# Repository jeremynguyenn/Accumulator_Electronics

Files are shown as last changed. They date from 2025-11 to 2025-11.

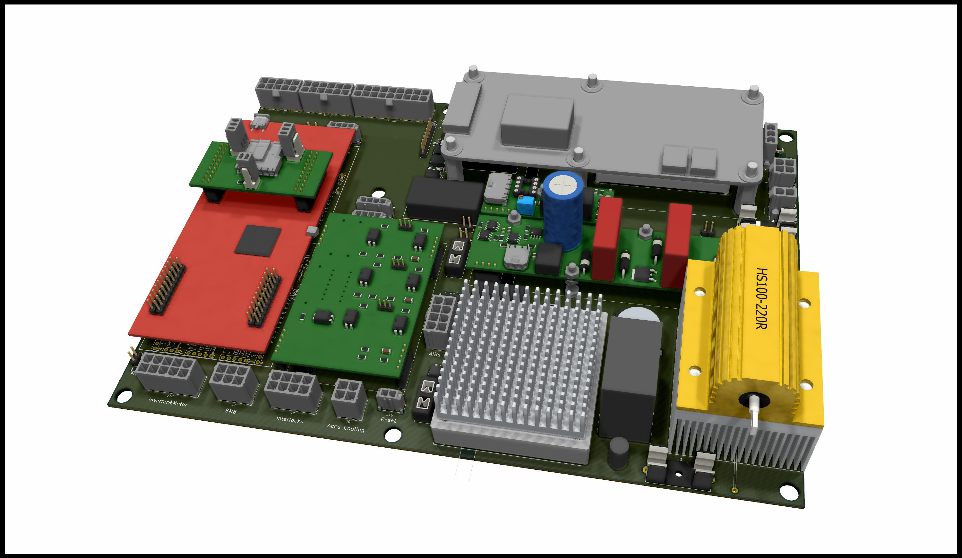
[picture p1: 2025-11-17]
Accumulator_Electronics/Accumulator Base/2021 Accumulator Base.png

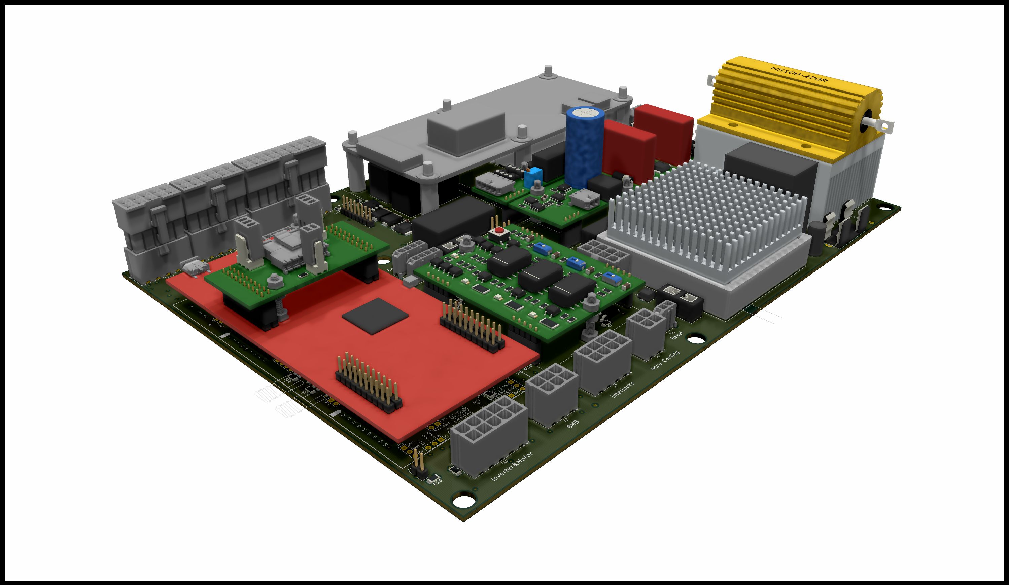
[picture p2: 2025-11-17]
Accumulator_Electronics/Accumulator Base/2021 Accumulator Base Final.png

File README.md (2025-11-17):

2021 Accumulator Base 2
2021 Accumulator Base Final
2021 Accumulator Base

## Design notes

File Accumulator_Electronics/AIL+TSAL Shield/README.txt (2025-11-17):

If all the CAD components can't be found in the 3D view is because some parts are referenced to a local folder
in another system. They can be downladed from the "KiCAD Libraries" repository found in Sabin's CADLAB.io account.
There is a link to such account in the team's GitHub, inside the "2021 Accumulator Electronics" repository.

**A component was created out of this PCB. It can be found in this very folder under "AIL&TSAL Library"

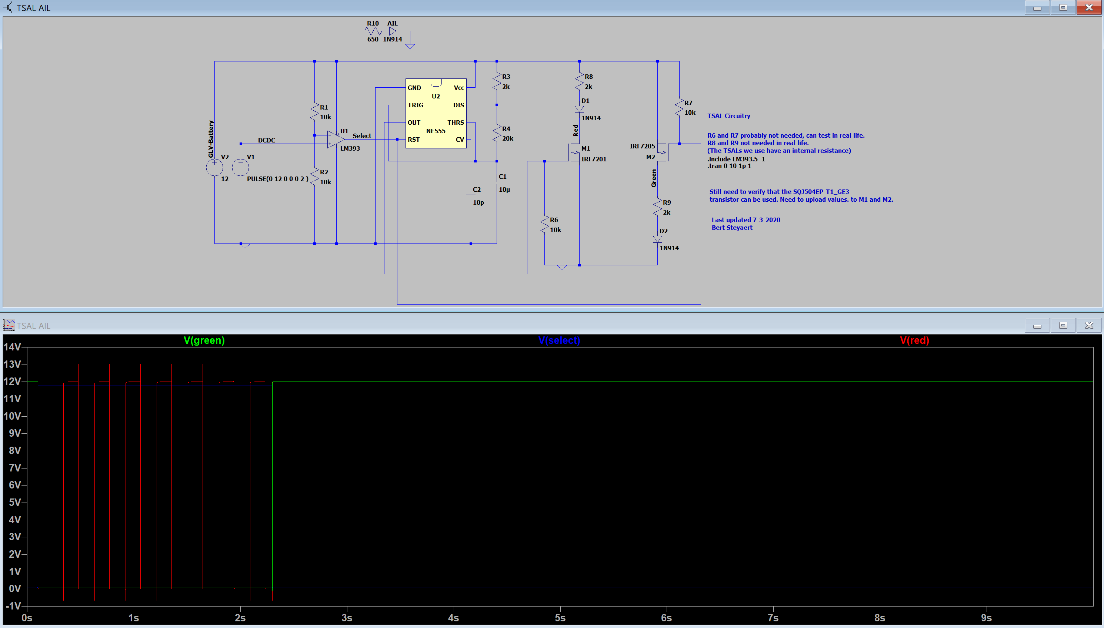
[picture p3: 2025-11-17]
Accumulator_Electronics/AIL+TSAL Shield/TSAL_Simulation/TSAL_final.png

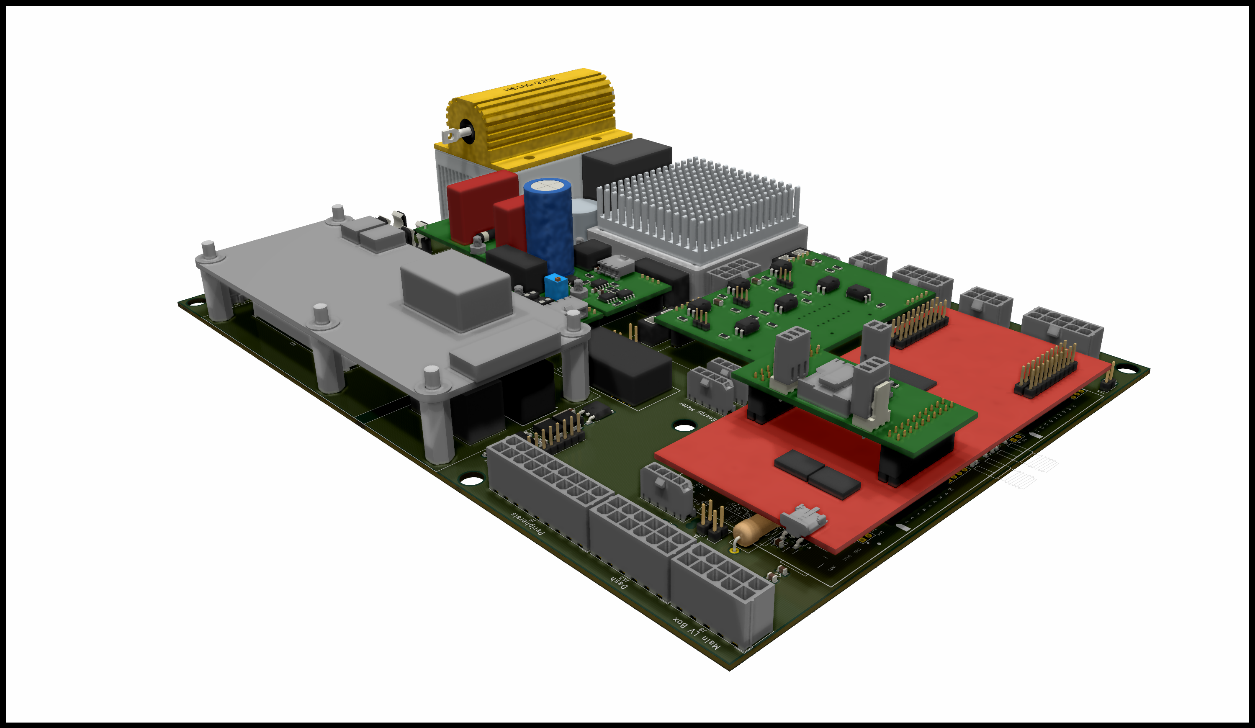
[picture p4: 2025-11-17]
Accumulator_Electronics/Accumulator Base/2021 Accumulator Base 2.png

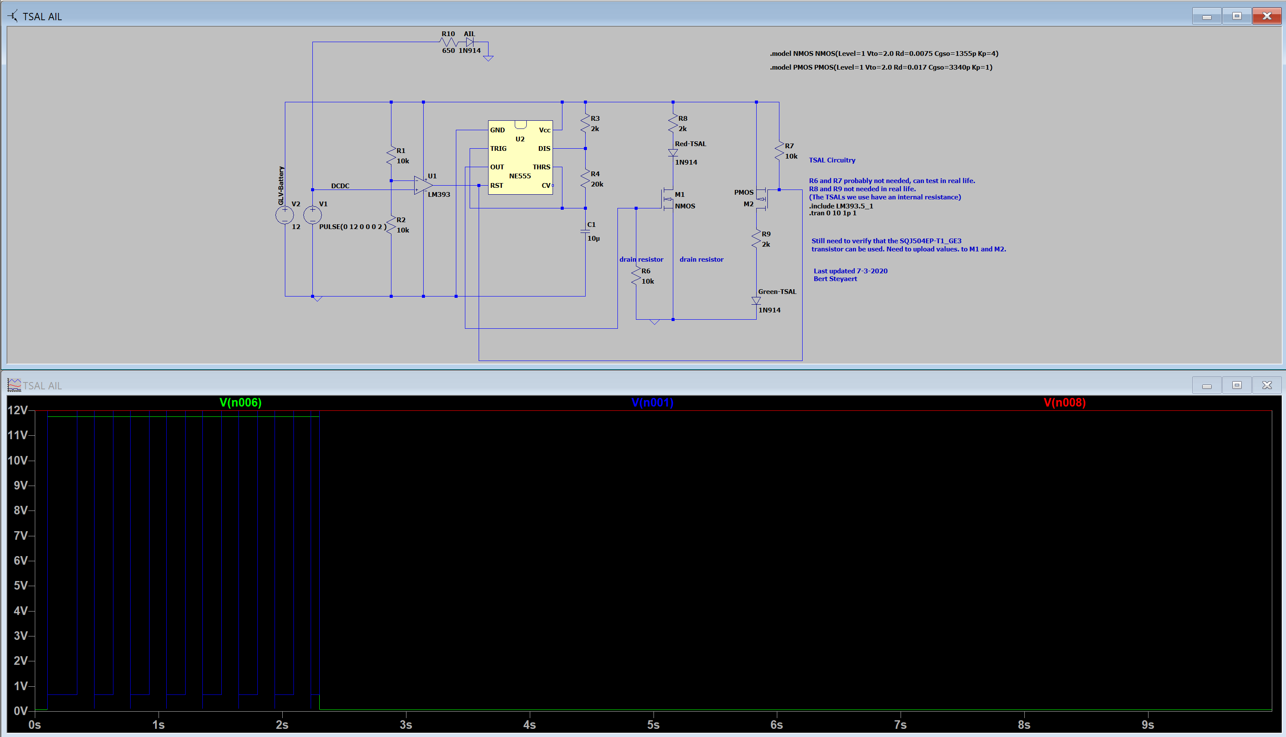
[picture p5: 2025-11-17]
Accumulator_Electronics/AIL+TSAL Shield/TSAL_Simulation/TSAL_SQJ504EP-T1_GE3.PNG

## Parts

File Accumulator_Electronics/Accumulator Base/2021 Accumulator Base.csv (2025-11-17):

Id | Designator | Package | Quantity | Designation | Supplier and ref
1 | U3 | SDC_9-8-20 | 1 | SDC_9-8-20
2 | U4 | LAUNCHXL-F28379D | 1 | LAUNCHXL-F28379D
3 | J3 | TE_MATE-N-LOK_1-770870-x_1x03_P4.14mm_Vertical | 1 | TSMP
4 | J10 | Molex_Mini-Fit_Jr_5566-10A_2x05_P4.20mm_Vertical | 1 | Inverter&Motor
5 | J2 | Molex_Mini-Fit_Jr_5566-06A_2x03_P4.20mm_Vertical | 1 | BMB
6 | J7 | Molex_Mini-Fit_Jr_5566-08A_2x04_P4.20mm_Vertical | 1 | Interlocks
7 | J6 | Molex_Mini-Fit_Jr_5566-04A_2x02_P4.20mm_Vertical | 1 | Accu Cooling
8 | J9 | Molex_Mini-Fit_Jr_5566-08A_2x04_P4.20mm_Vertical | 1 | AIRs
9 | C1 | CAPPRD250W50D655H1250 | 1 | 1u
10 | C2 | CAPAE1700X1700N | 1 | 10u
11 | C3,C5 | C_0805_2012Metric | 2 | 10u
12 | C4 | C_0805_2012Metric | 1 | 4.7u
13 | C6,C8,C10,C11,C12,C13,C14,C15,C16 | C_0805_2012Metric | 9 | 100n
14 | C7,C9 | C_0805_2012Metric | 2 | 10n
15 | D1,D2 | D_SMC | 2 | STTH212S
16 | D3,D4,D7 | D_0805_2012Metric | 3 | LED
17 | D5,D6 | D_SMC | 2 | D
18 | D8 | D_SOD-323 | 1 | DIODE
19 | F4 | Fuseholder_Blade_Mini_Keystone_3568 | 1 | 25A
20 | F6 | Fuseholder_Blade_Mini_Keystone_3568 | 1 | Fuse
21 | J11,J14,J15,J1,J18 | PinHeader_1x02_P2.54mm_Vertical | 5 | Jumper
22 | J16 | Molex_Micro-Fit_3.0_43650-0215_1x02_P3.00mm_Vertical | 1 | Reset button
23 | K1 | H3FA-A | 1 | Relay_H3FA-A-DC12
24 | L2 | L_1210_3225Metric | 1 | 10u
25 | Q1,Q2,Q3,Q4,Q6,Q7,Q8 | TO-252-2 | 7 | Q_NMOS_GDS
26 | Q5,Q10,Q11,Q12,Q13,Q14,Q15,Q16,Q17,Q18,Q19,Q20,Q21 | SOT-223-3_TabPin2 | 13 | Q_NMOS_GDS
27 | R1,R2,R7,R11,R17,R18,R19,R20,R21,R22,R23,R24,R25,R26,R27,R28,R29,R9,R13,R15,R30,R32,R33,R35,R36,R37,R38,R39,R40,R41,R42,R43,R44,R45,R46,R47,R48,R49 | R_1206_3216Metric | 38 | 10k
28 | R3,R4,R5,R14 | R_1206_3216Metric | 4 | 2k
29 | R6 | HS100 | 1 | HS100 2K F
30 | R8,R10,R12 | R_1206_3216Metric | 3 | NC
31 | R16 | R_1206_3216Metric | 1 | 120
32 | R31 | R_Axial_DIN0617_L17.0mm_D6.0mm_P20.32mm_Horizontal | 1 | R_US
33 | RV1 | Potentiometer_Vishay_TS53YJ_Vertical | 1 | TS53YJ501MR10
34 | U1 | 74HC86DR2G | 1 | 74HC86
35 | U5 | PWR_Transducer | 1 | PWR_Transducer
36 | U6 | Converter_DCDC_Murata_NCS1SxxxxSC_THT | 1 | NCS1S1212SC
37 | U8 | AIL&TSAL | 1 | AIL&TSAL
38 | U9 | TSOT-23-5 | 1 | LM3670MF
39 | U10 | G2RL112DC | 1 | G2RL-1-DC12.
40 | U11 | G2RL-24 | 1 | G2RL-24-DC12
41 | U12 | DBR71210 | 1 | DBR71210
42 | U13 | DAR71210 | 1 | DAR71210
43 | L1 | B82724J8612N040 | 1 | B82724J8612N040
44 | U2 | IMD | 1 | IMD
45 | U7 | QHL300 | 1 | QHL300
46 | F1,F2,F5 | Fuseholder_Cylinder-5x20mm_Schurter_0031_8201_Horizontal_Open | 3 | Fuse
47 | F3 | Fuseholder_Cylinder-5x20mm_Schurter_0031_8201_Horizontal_Open | 1 | 5A
48 | F7 | Fuse_1206_3216Metric | 1 | Fuse
49 | J4 | Molex_Mini-Fit_Jr_5566-04A2_2x02_P4.20mm_Vertical | 1 | Inv&Bat+
50 | J5 | Molex_Mini-Fit_Jr_5566-18A_2x09_P4.20mm_Vertical | 1 | Peripherals
51 | J8 | Molex_Mini-Fit_Jr_5566-10A_2x05_P4.20mm_Vertical | 1 | Main LV
52 | J12 | Molex_Micro-Fit_3.0_43650-0415_1x04_P3.00mm_Vertical | 1 | EnergyMeter-OUT
53 | J13 | Molex_Mini-Fit_Jr_5566-12A_2x06_P4.20mm_Vertical | 1 | Dash
54 | J17 | Molex_Mini-Fit_Jr_5566-02A2_2x01_P4.20mm_Vertical | 1 | Inverter-
55 | J19 | Molex_Micro-Fit_3.0_43650-0415_1x04_P3.00mm_Vertical | 1 | EnergyMeter-IN
56 | J20 | Molex_Micro-Fit_3.0_43650-0415_1x04_P3.00mm_Vertical | 1 | LCD

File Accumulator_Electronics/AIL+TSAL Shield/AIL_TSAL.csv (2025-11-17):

Id | Designator | Package | Quantity | Designation | Supplier and ref
1 | J3 | Molex_Micro-Fit_3.0_43650-0200_1x02_P3.00mm_Horizontal | 1 | Conn_01x02
2 | C1 | C_Rect_L27.0mm_W9.0mm_P22.00mm | 1 | 0.1uF
3 | C2 | C_Rect_L27.0mm_W9.0mm_P22.00mm | 1 | 1uF
4 | C3 | C_Radial_D16.0mm_H31.5mm_P7.50mm | 1 | 47uF
5 | C4 | C_0805_2012Metric | 1 | 27uF
6 | C5 | C_0805_2012Metric | 1 | 0.01u
7 | C6 | C_0805_2012Metric | 1 | 10u
8 | D1,D3 | D_5W_P10.16mm_Horizontal | 2 | DIODE
9 | D2 | D_5W_P10.16mm_Horizontal | 1 | D_Zener
10 | F1 | Fuse_1206_3216Metric | 1 | 50mA
11 | J1,J2 | Pin_D1.0mm_L10.0mm | 2 | Conn_01x01
12 | Q1 | SO-8_3.9x4.9mm_P1.27mm | 1 | Q_NMOS_SGD | IRF7201
13 | Q2 | SO-8_3.9x4.9mm_P1.27mm | 1 | Q_PMOS_SDG | IRF7205
14 | R1 | D_5W_P12.70mm_Horizontal | 1 | 48k
15 | R2 | D_5W_P12.70mm_Horizontal | 1 | 2k
16 | R3,R4,R8,R9 | R_1206_3216Metric | 4 | 10k
17 | R5 | R_1206_3216Metric | 1 | 650
18 | R6 | R_1206_3216Metric | 1 | 2k
19 | R7 | R_1206_3216Metric | 1 | 20k
20 | U1 | TO-252-2 | 1 | LR8K4-G
21 | U2 | PQP1-D24-D12-D | 1 | CRE1S0505DC | PQP1-D24-D12-D
22 | U3 | SOIC-8_3.9x4.9mm_P1.27mm | 1 | LM741 | LM393
23 | U4 | SOIC-8_3.9x4.9mm_P1.27mm | 1 | LM555
24 | J4 | PinHeader_1x04_P2.54mm_Vertical | 1 | Conn_01x04

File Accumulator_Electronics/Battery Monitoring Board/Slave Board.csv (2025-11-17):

Id | Designator | Package | Quantity | Designation | Supplier and ref
1 | J13 | Molex_Micro-Fit_3.0_43045-0800_2x04_P3.00mm_Horizontal | 1 | Conn_01x08
2 | U1 | MCP2515_ArduinoShield | 1 | MCP2551_CANmodule
3 | G***,G*** | flag | 2 | LOGO
4 | R12 | R_0805_2012Metric | 1 | NC
5 | J20,J14,J15,J16,J17,J18,J19,J21,J22,J23,J24,J25,J26 | TE_MATE-N-LOK_1-794374-x_1x01_P4.14mm_Horizontal | 13 | Conn_01x01
6 | C1,C3,C6,C7,C8,C9,C10,C11,C12,C13 | C_0805_2012Metric | 10 | 100n
7 | C2,C4,C5 | C_0805_2012Metric | 3 | 1u
8 | C14,C15,C16,C17,C18,C19,C20,C21,C22,C23,C24,C25 | C_0805_2012Metric | 12 | 10n
9 | D1 | D_1206_3216Metric | 1 | DIODE
10 | F1,F2,F3,F4,F5,F6,F7,F8,F9,F10,F11,F12,F13 | Fuse_1206_3216Metric | 13 | Fuse
11 | IC1 | SOP50P490X110-16N | 1 | LTC6820IMS#PBF
12 | IC2 | SOP50P780X200-48N | 1 | LTC6804-2
13 | J1,J2,J3,J4,J5,J6,J7,J8,J9,J10,J11,J12 | TE_MATE-N-LOK_1-770966-x_1x02_P4.14mm_Horizontal | 12 | Conn_01x02
14 | Q1 | SOT-223 | 1 | Q_NPN_BCE
15 | Q2,Q3,Q4,Q5,Q6,Q7,Q8,Q9,Q10,Q11,Q12,Q13 | SOT-23 | 12 | Q_PMOS_GSD
16 | R1,R2,R3,R4,R5,R6,R7,R8,R9,R10,R11,R60 | R_1206_3216Metric | 12 | 680
17 | R13 | R_0805_2012Metric | 1 | 5k
18 | R14,R15,R18,R22,R23,R25,R28,R31,R34,R37,R40,R43,R46,R49,R52,R55,R58 | R_0805_2012Metric | 17 | 100
19 | R16,R20 | R_0805_2012Metric | 2 | 1k21
20 | R17,R21 | R_0805_2012Metric | 2 | 860
21 | R19 | R_0805_2012Metric | 1 | 10k
22 | R24,R27,R30,R33,R36,R39,R42,R45,R48,R51,R54,R57 | R_0805_2012Metric | 12 | 3k3
23 | R26,R29,R32,R35,R38,R41,R44,R47,R50,R53,R56,R59 | R_0805_2012Metric | 12 | 33
24 | T1 | Pulse_PA2001NL | 1 | PE-68386NL
25 | U2 | SOIC-8_3.9x4.9mm_P1.27mm | 1 | MCP2551-I-SN
26 | U3 | SOT-223 | 1 | OKI-78SR-3.3_1.5-W36-C
27 | U4 | SOP-8_6.62x9.15mm_P2.54mm | 1 | ISO1050DUB
28 | U5 | Converter_DCDC_TRACO_POWER_TEL_10-xxxx_THT | 1 | TMR_1-1212
29 | U6 | Arduino_Micro_Socket | 1 | ARDUINO_MICRO_SHIELD
30 | J27 | Molex_KK-254_AE-6410-04A_1x04_P2.54mm_Vertical | 1 | Conn_01x04

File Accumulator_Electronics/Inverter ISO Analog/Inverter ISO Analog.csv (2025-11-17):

Id | Designator | Package | Quantity | Designation | Supplier and ref
1 | J4 | Molex_KK-254_AE-6410-03A_1x03_P2.54mm_Vertical | 1 | Accelerator Sensor
2 | J3 | Molex_KK-254_AE-6410-02A_1x02_P2.54mm_Vertical | 1 | Motor
3 | J2 | Molex_KK-254_AE-6410-03A_1x03_P2.54mm_Vertical | 1 | Brake Sensor
4 | J1 | Molex_Micro-Fit_3.0_43650-0500_1x05_P3.00mm_Horizontal | 1 | Inverter
5 | R1 | R_1206_3216Metric | 1 | 330k
6 | U1 | C2000BoosterPack_Shield | 1 | C2000BoosterPack_Shield

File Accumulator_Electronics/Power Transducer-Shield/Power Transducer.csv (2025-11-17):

Id | Designator | Package | Quantity | Designation | Supplier and ref
1 | RV1 | Potentiometer_ACP_CA9-H2,5_Horizontal | 1 | 100k
2 | C1 | C_0805_2012Metric | 1 | 10n
3 | C2,C7 | C_0805_2012Metric | 2 | 1u
4 | C3,C4,C5,C6 | C_0805_2012Metric | 4 | 0.1u
5 | D1,D2 | D_0805_2012Metric | 2 | DIODE
6 | IC1 | SOIC127P1150X280-8N | 1 | AMC1211AQDWVRQ1
7 | IC2 | DIP794W53P254L959H508Q8N | 1 | INA114AP
8 | J1,J2 | Pin_D1.0mm_L10.0mm | 2 | Conn_01x01
9 | J3 | Molex_Micro-Fit_3.0_43650-0400_1x04_P3.00mm_Horizontal | 1 | Conn_01x04
10 | J4 | PinHeader_1x05_P2.54mm_Vertical | 1 | Conn_01x05
11 | PS1 | Converter_DCDC_XP_POWER-ITXxxxxSA_THT | 1 | ITX0505SA
12 | R1,R2,R3 | R_1206_3216Metric | 3 | 3M
13 | R4 | R_1206_3216Metric | 1 | 59k

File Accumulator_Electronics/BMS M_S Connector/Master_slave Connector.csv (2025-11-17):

Id | Designator | Package | Quantity | Designation | Supplier and ref
1 | J2,J3,J4,J5,J6,J7 | Molex_Micro-Fit_3.0_43045-0812_2x04_P3.00mm_Vertical | 6 | Conn_01x08
2 | J1 | Molex_Mini-Fit_Jr_5566-06A_2x03_P4.20mm_Vertical | 1 | Conn_01x06
3 | J8 | Molex_Mini-Fit_Jr_5566-04A_2x02_P4.20mm_Vertical | 1 | Conn_01x04

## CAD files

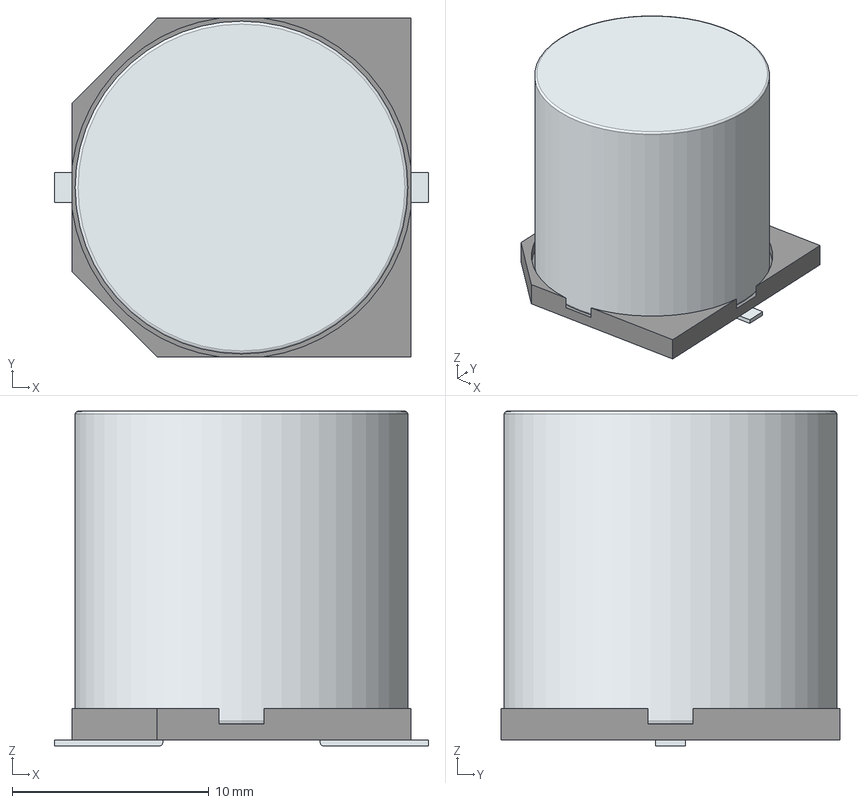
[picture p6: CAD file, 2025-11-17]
Accumulator_Electronics/Accumulator Base/EEV-EB2V100SM/3D/EEV-EB2V100SM.stp
19.0 x 17.2 x 17.0 mm
Base
Pin1Fillet
Pin2Fillet

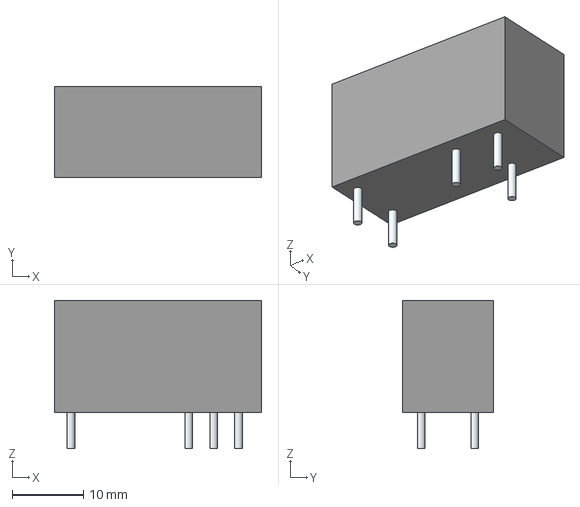
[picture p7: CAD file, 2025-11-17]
Accumulator_Electronics/Accumulator Base/G2RL-1_12DC/3D/G2RL-1_12DC.stp
29.0 x 12.7 x 20.8 mm
Leads x 5

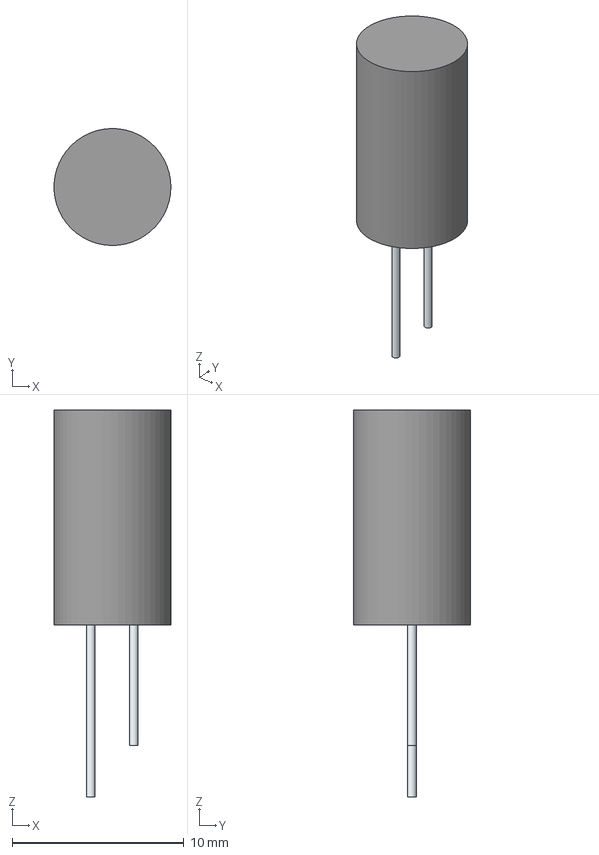
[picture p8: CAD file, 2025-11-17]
Accumulator_Electronics/Accumulator Base/UVR2V010MED/3D/UVR2V010MED.stp
6.79 x 6.80 x 22.5 mm
SimpleBody
Pin1
Pin2

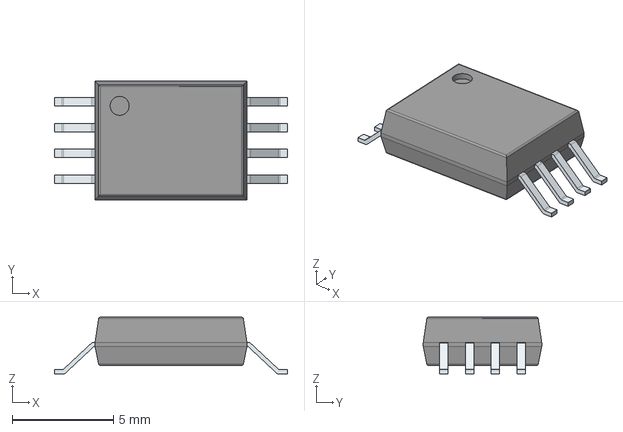
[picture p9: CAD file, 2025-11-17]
Accumulator_Electronics/Power Transducer-Shield/07-02-2020/AMC1211AQDWVRQ1/3D/AMC1211AQDWVRQ1.stp
11.5 x 5.85 x 2.80 mm
PinsArrayLR

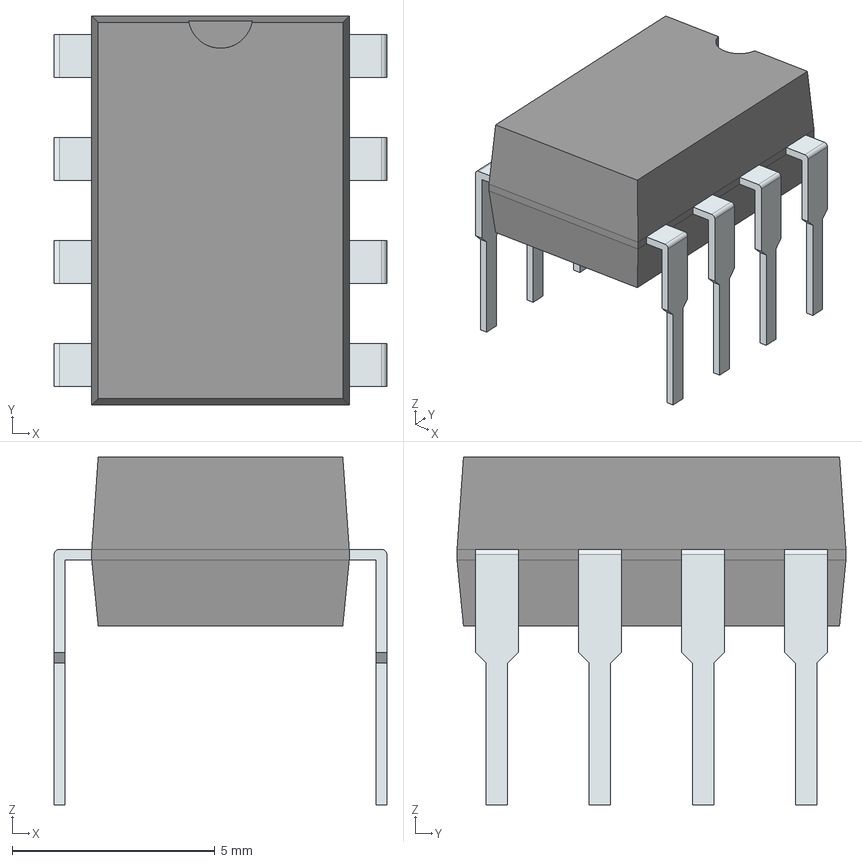
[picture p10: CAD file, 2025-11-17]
Accumulator_Electronics/Power Transducer-Shield/07-02-2020/INA114AP/3D/INA114AP.stp
8.21 x 9.59 x 8.58 mm
PinsArrayLR

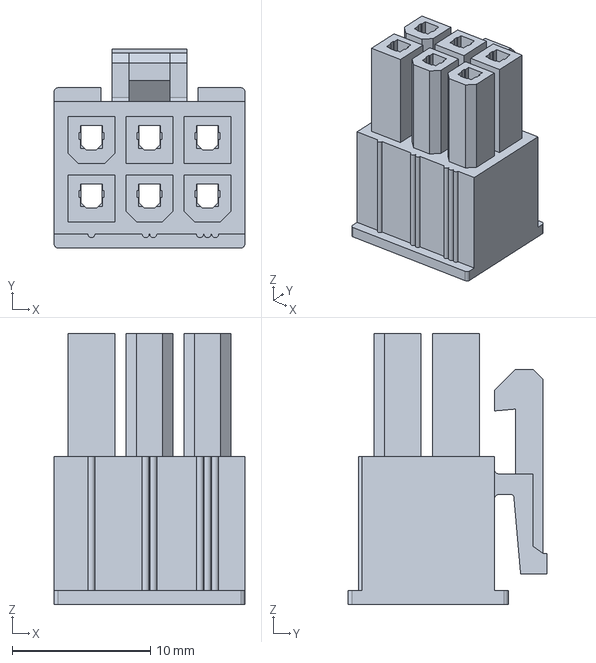
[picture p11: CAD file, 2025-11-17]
Accumulator_Electronics/BMS M_S Connector/8-1-2020/3D/39-01-2060.stp
13.8 x 14.4 x 19.6 mm

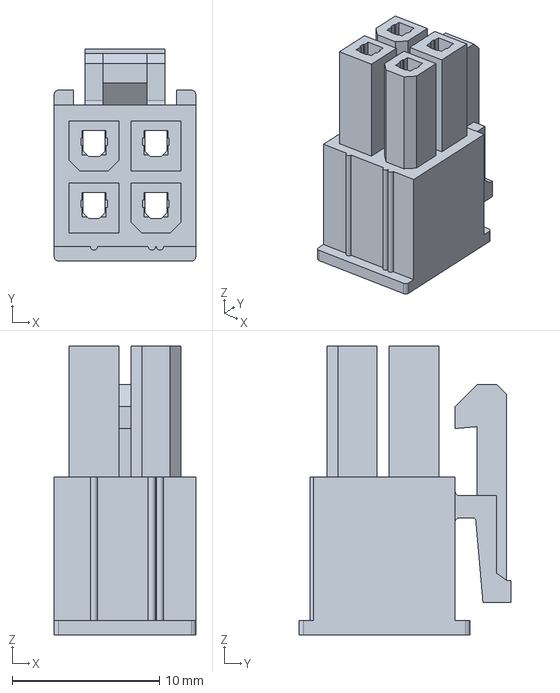
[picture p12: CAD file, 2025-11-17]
Accumulator_Electronics/BMS M_S Connector/8-1-2020/3D/39-01-2045.stp
9.60 x 14.4 x 19.6 mm

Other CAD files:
Accumulator_Electronics/Accumulator Base/2021 Accumulator Base.step
Accumulator_Electronics/Accumulator Base/CAD Models/1 Row Female Pin Header Pitch 2.54mm Height 8.5mm/Female Pin Header 01x05 Pitch 2.54mm Height 8.5mm.stp
Accumulator_Electronics/Accumulator Base/CAD Models/Accumulator Box/SDC_module v1.step
Accumulator_Electronics/AIL+TSAL Shield/07-10-2020/AIL_TSAL.step
Accumulator_Electronics/Battery Monitoring Board/09-07-2020 BMB/LTC6804-2/3D/LTC6804-2.stp
Accumulator_Electronics/Battery Monitoring Board/09-07-2020 BMB/LTC6820IMS#PBF/3D/LTC6820IMS#PBF.stp
Accumulator_Electronics/Battery Monitoring Board/09-07-2020 BMB/Slave Board.step
Accumulator_Electronics/BMS M_S Connector/8-1-2020/Master_slave Connector.step
Accumulator_Electronics/Inverter ISO Analog/Inverter ISO Analog.step
Accumulator_Electronics/Power Transducer-Shield/07-02-2020/Power Transducer.step
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

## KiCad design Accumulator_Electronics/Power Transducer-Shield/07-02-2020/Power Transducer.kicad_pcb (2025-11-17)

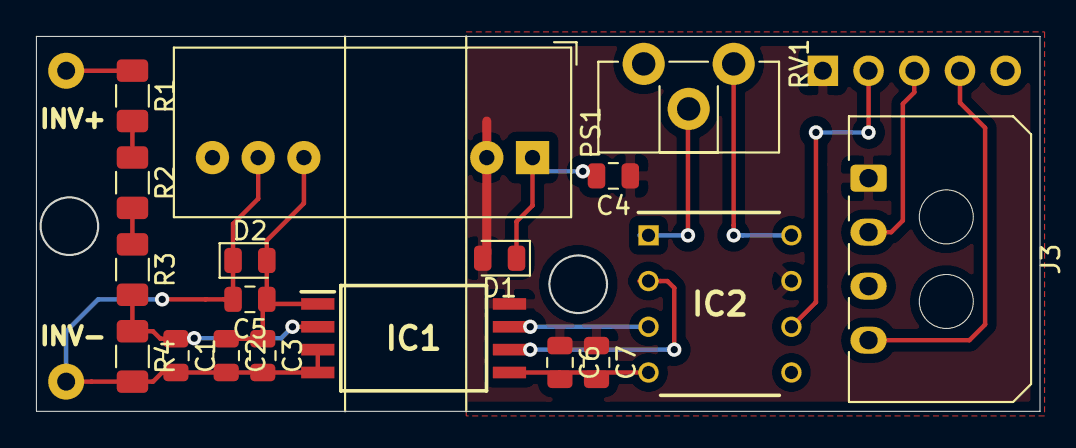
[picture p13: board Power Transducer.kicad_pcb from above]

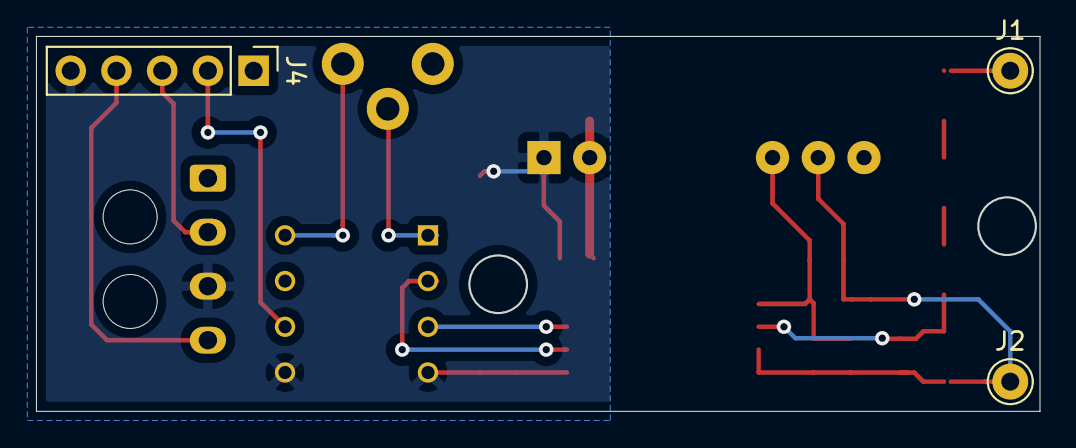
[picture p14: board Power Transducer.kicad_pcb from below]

Board: 2 copper layers, 55.8 x 20.8 mm, 21 parts (3 on the bottom side), 15 nets.

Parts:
C1: 10n; C_0805_2012Metric
C2, C7: 1u; C_0805_2012Metric
C3, C4, C5, C6: 0.1u; C_0805_2012Metric
D1, D2: DIODE; D_0805_2012Metric
IC1: AMC1211AQDWVRQ1; SOIC127P1150X280-8N
IC2: INA114AP; DIP794W53P254L959H508Q8N
J1, J2: Conn_01x01; Pin_D1.0mm_L10.0mm
J3: Conn_01x04; Molex_Micro-Fit_3.0_43650-0400_1x04_P3.00mm_Horizontal
J4: Conn_01x05; PinHeader_1x05_P2.54mm_Vertical
PS1: ITX0505SA; Converter_DCDC_XP_POWER-ITXxxxxSA_THT
R1, R2, R3: 3M; R_1206_3216Metric
R4: 59k; R_1206_3216Metric
RV1: 100k; Potentiometer_ACP_CA9-H2,5_Horizontal

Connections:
+5V: C4.1, C6.1, C7.1, D1.2, IC1.8, IC2.7, J3.1, J4.1, PS1.2
GND: C4.2, C6.2, C7.2, D1.1, IC1.5, IC2.4, IC2.5, J3.3, J4.5, PS1.1
HV_Sens: IC2.6, J4.2
High_C_Meas: J3.2, J4.3
Inv+: J1.1, R1.1
Inv-: C1.2, C2.2, C3.2, C5.2, D2.1, IC1.3, IC1.4, J2.1, PS1.7, R4.2
Low_C_Meas: J3.4, J4.4
unnamed: C1.1, IC1.2, R3.2, R4.1
unnamed: IC1.6, IC2.2
unnamed: IC1.7, IC2.3
unnamed: IC2.1, RV1.2
unnamed: IC2.8, RV1.1
unnamed: R1.2, R2.1
unnamed: R2.2, R3.1
VDD1: C2.1, C3.1, C5.1, D2.2, IC1.1, PS1.6

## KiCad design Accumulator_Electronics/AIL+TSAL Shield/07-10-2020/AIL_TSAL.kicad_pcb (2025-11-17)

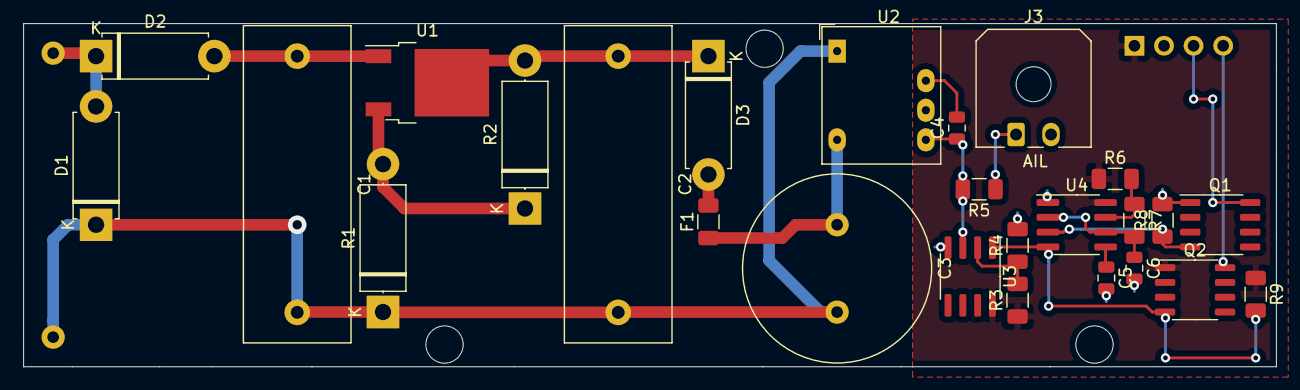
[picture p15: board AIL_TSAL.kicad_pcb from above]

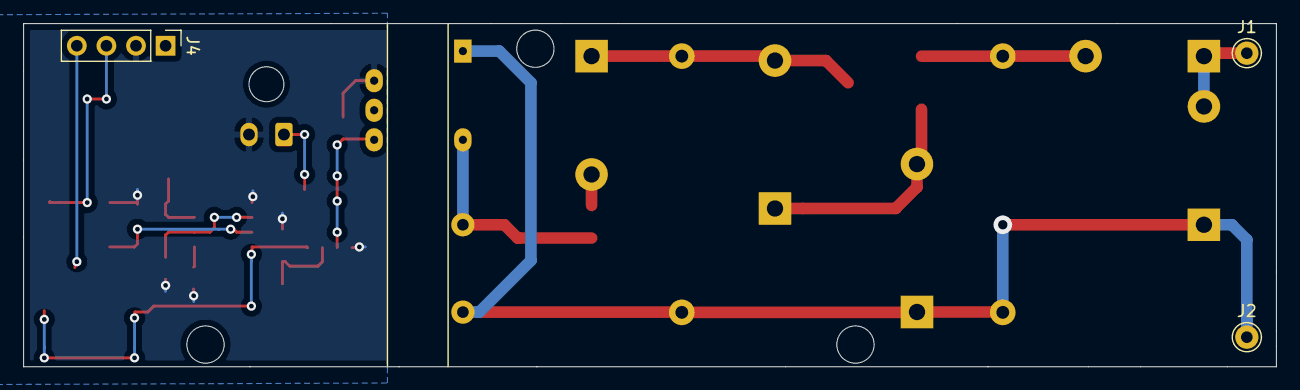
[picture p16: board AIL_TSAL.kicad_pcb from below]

Board: 2 copper layers, 107.6 x 29.5 mm, 29 parts (3 on the bottom side), 19 nets.

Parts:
C1: 0.1uF; C_Rect_L27.0mm_W9.0mm_P22.00mm
C2: 1uF; C_Rect_L27.0mm_W9.0mm_P22.00mm
C3: 47uF; C_Radial_D16.0mm_H31.5mm_P7.50mm
C4: 27uF; C_0805_2012Metric
C5: 0.01u; C_0805_2012Metric
C6: 10u; C_0805_2012Metric
D1, D3: DIODE; D_5W_P10.16mm_Horizontal
D2: D_Zener; D_5W_P10.16mm_Horizontal
F1: 50mA; Fuse_1206_3216Metric
J1, J2: Conn_01x01; Pin_D1.0mm_L10.0mm
J3: Conn_01x02; Molex_Micro-Fit_3.0_43650-0200_1x02_P3.00mm_Horizontal
J4: Conn_01x04; PinHeader_1x04_P2.54mm_Vertical
Q1: Q_NMOS_SGD; SO-8_3.9x4.9mm_P1.27mm
Q2: Q_PMOS_SDG; SO-8_3.9x4.9mm_P1.27mm
R1: 48k; D_5W_P12.70mm_Horizontal
R2: 2k; D_5W_P12.70mm_Horizontal
R3, R4, R8, R9: 10k; R_1206_3216Metric
R5: 650; R_1206_3216Metric
R6: 2k; R_1206_3216Metric
R7: 20k; R_1206_3216Metric
U1: LR8K4-G; TO-252-2
U2: CRE1S0505DC; PQP1-D24-D12-D
U3: LM741; SOIC-8_3.9x4.9mm_P1.27mm
U4: LM555; SOIC-8_3.9x4.9mm_P1.27mm

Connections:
+12V: J4.1, Q2.1, R3.1, R6.1, R9.1, U3.8, U4.8
/Sheet5F0851A9/Inv+: D1.2, D2.1, J1.1
/Sheet5F0851A9/Inv-: C1.2, C2.2, C3.2, D1.1, J2.1, R1.1, U2.1
GND: C4.2, C5.2, C6.2, J3.2, J4.2, Q1.1, R4.2, R8.2, U2.7, U3.4, U4.1
Green+: J4.4, Q2.8
unnamed: C1.1, D2.2, U1.1
unnamed: C2.1, D3.1, R2.2, U1.2
unnamed: C3.1, F1.1, U2.4
unnamed: C4.1, R5.2, U2.5, U3.3
unnamed: C5.1, U4.5
unnamed: C6.1, R7.2, U4.2, U4.6
unnamed: D3.2, F1.2
unnamed: J3.1, R5.1
unnamed: Q1.4, R8.1, U4.3
unnamed: Q2.4, R9.2, U3.1, U4.4
unnamed: R1.2, R2.1, U1.3
unnamed: R3.2, R4.1, U3.2
unnamed: R6.2, R7.1, U4.7
Red-: J4.3, Q1.8

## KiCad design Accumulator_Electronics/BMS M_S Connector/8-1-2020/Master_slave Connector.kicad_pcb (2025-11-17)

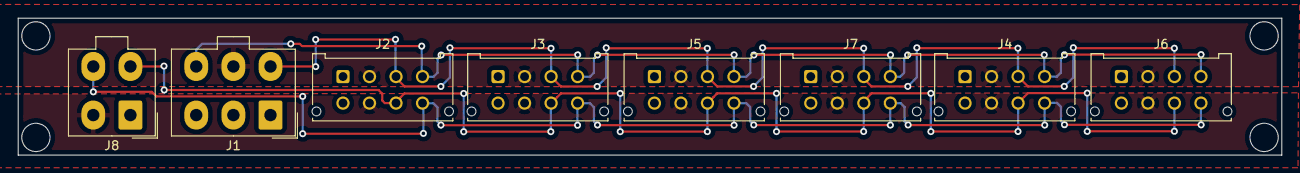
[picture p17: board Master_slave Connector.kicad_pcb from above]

Board: 2 copper layers, 143.0 x 15.5 mm, 8 parts (0 on the bottom side), 7 nets.

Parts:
J1: Conn_01x06; Molex_Mini-Fit_Jr_5566-06A_2x03_P4.20mm_Vertical
J2, J3, J4, J5, J6, J7: Conn_01x08; Molex_Micro-Fit_3.0_43045-0812_2x04_P3.00mm_Vertical
J8: Conn_01x04; Molex_Mini-Fit_Jr_5566-04A_2x02_P4.20mm_Vertical

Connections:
+12V: J1.5, J2.2, J3.2, J4.2, J5.2, J6.2, J7.2
CANH: J1.4, J2.3, J3.3, J4.3, J5.3, J6.3, J7.3
CANL: J1.6, J2.4, J3.4, J4.4, J5.4, J6.4, J7.4
DCDC+: J2.6, J3.6, J4.6, J5.6, J6.6, J7.6, J8.2
GND: J1.1, J1.2, J2.1, J2.5, J3.1, J3.5, J4.1, J4.5, J5.1, J5.5, J6.1, J6.5, J7.1, J7.5, J8.1
PWM: J2.8, J3.8, J4.8, J5.8, J6.8, J7.8, J8.4
Sens: J2.7, J3.7, J4.7, J5.7, J6.7, J7.7, J8.3

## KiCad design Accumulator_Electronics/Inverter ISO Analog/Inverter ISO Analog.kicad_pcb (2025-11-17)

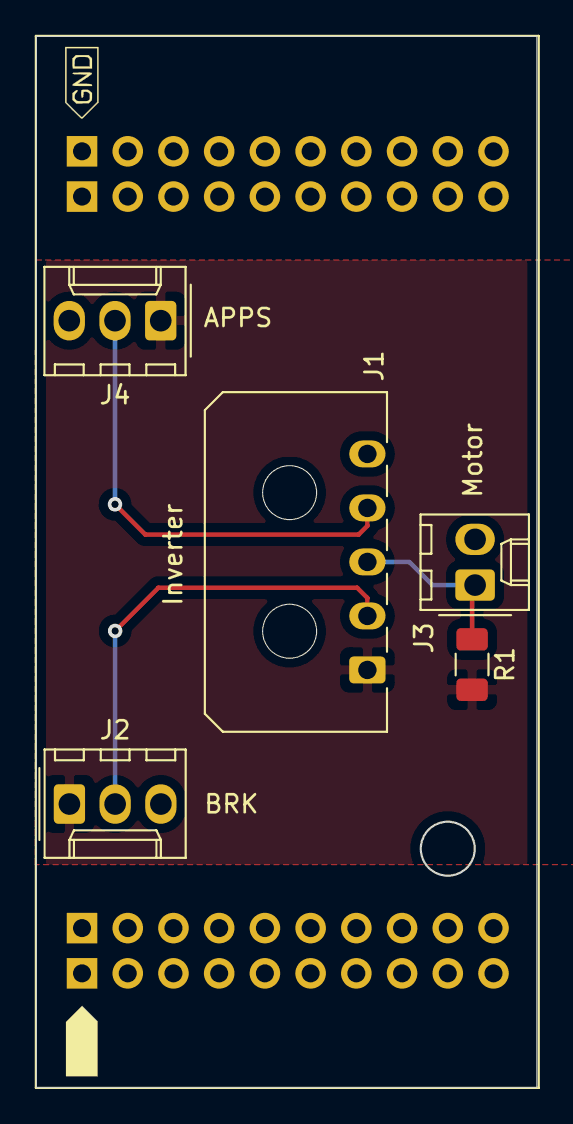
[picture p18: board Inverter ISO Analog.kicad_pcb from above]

Board: 2 copper layers, 27.8 x 58.4 mm, 6 parts (0 on the bottom side), 5 nets.

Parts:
J1: Inverter; Molex_Micro-Fit_3.0_43650-0500_1x05_P3.00mm_Horizontal
J2: Brake Sensor; Molex_KK-254_AE-6410-03A_1x03_P2.54mm_Vertical
J3: Motor; Molex_KK-254_AE-6410-02A_1x02_P2.54mm_Vertical
J4: Accelerator Sensor; Molex_KK-254_AE-6410-03A_1x03_P2.54mm_Vertical
R1: 330k; R_1206_3216Metric
U1: C2000BoosterPack_Shield

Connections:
+5V: J1.1, J2.1, J4.1, R1.2
APPS: J1.4, J4.2
BRK: J1.2, J2.2
GNDA: J1.5, J2.3, J3.2, J4.3
Therm+: J1.3, J3.1, R1.1

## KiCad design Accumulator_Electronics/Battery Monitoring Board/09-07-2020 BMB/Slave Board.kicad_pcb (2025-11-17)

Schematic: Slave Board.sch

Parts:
C1, C3, C6, C7, C8, C9, C10, C11, C12, C13: 100n; C_0805_2012Metric
C2, C4, C5: 1u; C_0805_2012Metric
D1: DIODE; D_1206_3216Metric
F13: Fuse; Fuse_1206_3216Metric
IC1: LTC6820IMS#PBF; SOP50P490X110-16N; Manufacturer_Part_Number LTC6820IMS#PBF; Mouser Part Number 584-LTC6820IMS#PBF
IC2: LTC6804-2; SOP50P780X200-48N; Manufacturer_Part_Number LTC6804-2
J1, J2, J3, J4, J5, J6, J7, J8, J9, J10, J11, J12: Conn_01x02; TE_MATE-N-LOK_1-770966-x_1x02_P4.14mm_Horizontal
J13: Conn_01x08; Molex_Micro-Fit_3.0_43045-0800_2x04_P3.00mm_Horizontal
J26: Conn_01x01; TE_MATE-N-LOK_1-794374-x_1x01_P4.14mm_Horizontal
J27: Conn_01x04; Molex_KK-254_AE-6410-04A_1x04_P2.54mm_Vertical
Q1: Q_NPN_BCE; SOT-223
R1, R2, R3, R4, R5, R6, R7, R8, R9, R10, R11, R60: 680; R_1206_3216Metric
R12: NC; R_0805_2012Metric
R13: 5k; R_0805_2012Metric
R14, R15, R18, R22, R23: 100; R_0805_2012Metric
R16, R20: 1k21; R_0805_2012Metric
R17, R21: 860; R_0805_2012Metric
R19: 10k; R_0805_2012Metric
T1: PE-68386NL; Pulse_PA2001NL
U1: MCP2551_CANmodule; MCP2515_ArduinoShield
U2: MCP2551-I-SN; SOIC-8_3.9x4.9mm_P1.27mm
U3: OKI-78SR-3.3_1.5-W36-C; SOT-223
U4: ISO1050DUB; SOP-8_6.62x9.15mm_P2.54mm
U5: TMR_1-1212; Converter_DCDC_TRACO_POWER_TEL_10-xxxx_THT
U6: ARDUINO_MICRO_SHIELD; Arduino_Micro_Socket

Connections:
+5V: C1.1, C6.1, C13.1, IC1.1, IC1.6, IC1.7, IC1.8, IC1.9, IC1.12, R1.1, R2.1, R3.1, R4.1, R5.1, R6.1, R7.1, R8.1, R9.1, R10.1, R11.1, R13.1, R60.1, U1.7, U4.8, U6.5V (+5V)
+12V: C7.1, C11.1, D1.2, J13.2, U3.3, U5.2
C0: C2.2, C3.1, C4.2, C5.2, C9.1, IC2.26, IC2.30, IC2.31, IC2.45, IC2.46, IC2.47, IC2.48, R17.1; also elsewhere on the board
C1: IC2.24; also elsewhere on the board
C2: IC2.22; also elsewhere on the board
C3: IC2.20; also elsewhere on the board
C4: IC2.18; also elsewhere on the board
C5: IC2.16; also elsewhere on the board
C6: IC2.14; also elsewhere on the board
C7: IC2.12; also elsewhere on the board
C8: IC2.10; also elsewhere on the board
C9: IC2.8; also elsewhere on the board
C10: IC2.6; also elsewhere on the board
C11: IC2.4; also elsewhere on the board
C12: IC2.2, R22.2; also elsewhere on the board
CANH: J13.3, U2.7
CANL: J13.4, U2.6
CS: IC1.5, R12.1, U1.5, U6.SS (RX_LED/SS)
Cell4: R14.2; also elsewhere on the board
Cell12: F13.2, R22.1, R23.2; also elsewhere on the board
DCDC+: J13.6, J27.2
DRV: IC2.38, Q1.1
GND: C7.2, C8.2, C10.2, C11.2, D1.1, J13.1, J13.5, J27.1, R19.2, U2.2, U3.2, U4.4, U5.1
GND_ISO: C1.2, C6.2, C12.2, C13.2, IC1.13, IC1.14, J1.1, J2.1, J3.1, J4.1, J5.1, J6.1, J7.1, J8.1, J9.1, J10.1, J11.1, J12.1, R21.2, U1.6, U4.5, U5.6, U6.GND
IM: IC1.10, R15.1, T1.3
IMA: IC2.41, R18.1, T1.4
IP: IC1.11, R15.2, T1.1
IPA: IC2.42, R18.2, T1.6
ISO_CANH: U1.8, U4.7
ISO_CANL: U1.9, U4.6
unnamed: C3.2, Q1.2, R14.1
unnamed: C4.1, IC2.35
unnamed: C5.1, IC2.34
unnamed: C9.2, IC2.1, R23.1
unnamed: F13.1, J26.1
unnamed: IC1.15, R20.2, R21.1
unnamed: IC1.16, R20.1
unnamed: IC2.43, R16.1, R17.2
unnamed: IC2.44, R16.2
unnamed: R12.2, U6.TX (1/TX)
unnamed: R19.1, U2.8
PWM_Fans: J13.8, J27.4
RXD: U2.4, U4.2
S1: IC2.25; also elsewhere on the board
S2: IC2.23; also elsewhere on the board
S3: IC2.21; also elsewhere on the board
S4: IC2.19; also elsewhere on the board
S5: IC2.17; also elsewhere on the board
S6: IC2.15; also elsewhere on the board
S7: IC2.13; also elsewhere on the board
S8: IC2.11; also elsewhere on the board
S9: IC2.9; also elsewhere on the board
S10: IC2.7; also elsewhere on the board
S11: IC2.5; also elsewhere on the board
S12: IC2.3; also elsewhere on the board
SCK: IC1.4, U1.2, U6.SCK
SI: IC1.2, U1.3, U6.MO (MOSI)
SO: IC1.3, R13.2, U1.4, U6.MI (MISO)
Sens_Fans: J13.7, J27.3
T0: J1.2, R1.2, U6.A0
T1: J2.2, R2.2, U6.A1
T2: J3.2, R3.2, U6.A2
T3: J4.2, R4.2, U6.A3
T4: J5.2, R5.2, U6.A4
T5: J6.2, R6.2, U6.A5
T6: J7.2, R7.2, U6.4 (4/A6)
T7: J8.2, R8.2, U6.6 (6(PWM)/A7)
T8: J9.2, R9.2, U6.8 (8/A8)
T9: J10.2, R10.2, U6.9 (9(PWM)/A9)
T10: J11.2, R11.2, U6.10 (10(PWM)/A10)
T11: J12.2, R60.2, U6.12 (12/A11)
TXD: U2.1, U4.3
VCC: C8.1, C10.1, U2.3, U3.1, U4.1
VCC_ISO: C12.1, U5.4, U6.VI (VIN)
Vreg: C2.1, IC2.37, IC2.40, Q1.3

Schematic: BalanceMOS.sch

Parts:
C14: 10n; C_0805_2012Metric
F1: Fuse; Fuse_1206_3216Metric
J20: Conn_01x01; TE_MATE-N-LOK_1-794374-x_1x01_P4.14mm_Horizontal
Q2: Q_PMOS_GSD; SOT-23
R24: 3k3; R_0805_2012Metric
R25: 100; R_0805_2012Metric
R26: 33; R_0805_2012Metric

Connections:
C6: C14.2, R25.2; also elsewhere on the board
C7: C14.1; also elsewhere on the board
Cell6: F1.2, R25.1, R26.1; also elsewhere on the board
Cell7: Q2.3; also elsewhere on the board
unnamed 45: F1.1; also elsewhere on the board
unnamed 51: J20.1; also elsewhere on the board
unnamed: Q2.1, R24.1
unnamed: Q2.2, R26.2
S7: R24.2; also elsewhere on the board

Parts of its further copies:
C15, C16, C17, C18, C19, C20, C21, C22, C23, C24, C25: 10n; C_0805_2012Metric
F2, F3, F4, F5, F6, F7, F8, F9, F10, F11, F12: Fuse; Fuse_1206_3216Metric
J14, J15, J16, J17, J18, J19, J21, J22, J23, J24, J25: Conn_01x01; TE_MATE-N-LOK_1-794374-x_1x01_P4.14mm_Horizontal
Q3, Q4, Q5, Q6, Q7, Q8, Q9, Q10, Q11, Q12, Q13: Q_PMOS_GSD; SOT-23
R27, R30, R33, R36, R39, R42, R45, R48, R51, R54, R57: 3k3; R_0805_2012Metric
R28, R31, R34, R37, R40, R43, R46, R49, R52, R55, R58: 100; R_0805_2012Metric
R29, R32, R35, R38, R41, R44, R47, R50, R53, R56, R59: 33; R_0805_2012Metric

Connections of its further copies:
C0: C20.2, R43.2; also elsewhere on the board
C1: C20.1, C21.2, R46.2; also elsewhere on the board
C2: C21.1, C22.2, R49.2; also elsewhere on the board
C3: C22.1, C23.2, R52.2; also elsewhere on the board
C4: C23.1, C24.2, R55.2; also elsewhere on the board
C5: C24.1, C25.2, R58.2; also elsewhere on the board
C6: C25.1; also elsewhere on the board
C7: C15.2, R28.2; also elsewhere on the board
C8: C15.1, C16.2, R31.2; also elsewhere on the board
C9: C16.1, C17.2, R34.2; also elsewhere on the board
C10: C17.1, C18.2, R37.2; also elsewhere on the board
C11: C18.1, C19.2, R40.2; also elsewhere on the board
C12: C19.1; also elsewhere on the board
Cell0: F7.2, R43.1, R44.1
Cell1: F8.2, Q8.3, R46.1, R47.1
Cell2: F9.2, Q9.3, R49.1, R50.1
Cell3: F10.2, Q10.3, R52.1, R53.1
Cell4: F11.2, Q11.3, R55.1, R56.1; also elsewhere on the board
Cell5: F12.2, Q12.3, R58.1, R59.1
Cell6: Q13.3; also elsewhere on the board
Cell7: F2.2, R28.1, R29.1; also elsewhere on the board
Cell8: F3.2, Q3.3, R31.1, R32.1
Cell9: F4.2, Q4.3, R34.1, R35.1
Cell10: F5.2, Q5.3, R37.1, R38.1
Cell11: F6.2, Q6.3, R40.1, R41.1
Cell12: Q7.3; also elsewhere on the board
unnamed 45: J14.1; also elsewhere on the board
unnamed: F2.1, J15.1
unnamed: F3.1, J16.1
unnamed: F4.1, J17.1
unnamed: F5.1, J18.1
unnamed: F6.1, J19.1
unnamed 51: F7.1; also elsewhere on the board
unnamed: F8.1, J21.1
unnamed: F9.1, J22.1
unnamed: F10.1, J23.1
unnamed: F11.1, J24.1
unnamed: F12.1, J25.1
unnamed: Q3.1, R27.1
unnamed: Q3.2, R29.2
unnamed: Q4.1, R30.1
unnamed: Q4.2, R32.2
unnamed: Q5.1, R33.1
unnamed: Q5.2, R35.2
unnamed: Q6.1, R36.1
unnamed: Q6.2, R38.2
unnamed: Q7.1, R39.1
unnamed: Q7.2, R41.2
unnamed: Q8.1, R42.1
unnamed: Q8.2, R44.2
unnamed: Q9.1, R45.1
unnamed: Q9.2, R47.2
unnamed: Q10.1, R48.1
unnamed: Q10.2, R50.2
unnamed: Q11.1, R51.1
unnamed: Q11.2, R53.2
unnamed: Q12.1, R54.1
unnamed: Q12.2, R56.2
unnamed: Q13.1, R57.1
unnamed: Q13.2, R59.2
S1: R42.2; also elsewhere on the board
S2: R45.2; also elsewhere on the board
S3: R48.2; also elsewhere on the board
S4: R51.2; also elsewhere on the board
S5: R54.2; also elsewhere on the board
S6: R57.2; also elsewhere on the board
S8: R27.2; also elsewhere on the board
S9: R30.2; also elsewhere on the board
S10: R33.2; also elsewhere on the board
S11: R36.2; also elsewhere on the board
S12: R39.2; also elsewhere on the board

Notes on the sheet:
Resistor between C0 and Cell0 is a SC

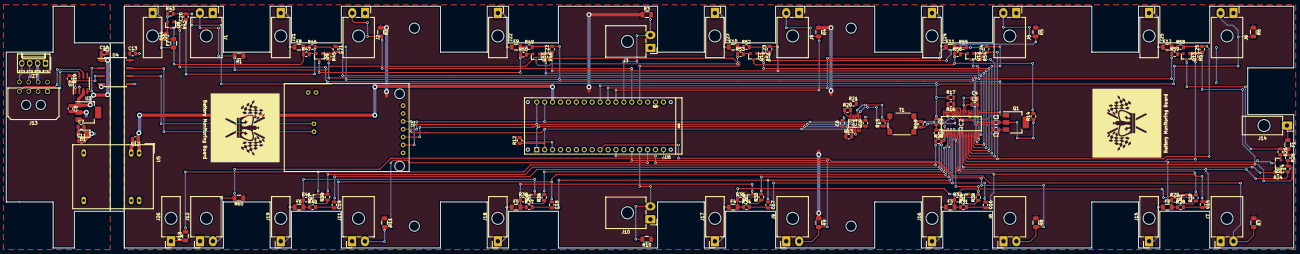
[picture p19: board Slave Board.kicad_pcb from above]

Board: 2 copper layers, 412.7 x 77.5 mm, 148 parts (0 on the bottom side), 122 nets.
